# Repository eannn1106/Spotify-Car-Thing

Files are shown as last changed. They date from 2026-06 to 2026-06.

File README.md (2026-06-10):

# Spotify Car Thing_v1
A designated spotify display that can control playback, fetch track information including song duration, song artist, song album and displays lyrics. This spotify display is specially modified to fit in among non-coders by logging in wifi credentials throughout captive portal.
However for the one-time authentication part from Spotify API have to done it through a serial monitor by running the given code. 

****Note this device requires Spotify Premium and external sound system e.g. phone, laptop, speaker**


# Why I want to build this?
- A spotify car thing manufactured from Spotify costs over 30 USD, and for aesthetics reasons, I think that it is cool to have one sitting right in front of the car dashboard.
- The original spotify car thing doesn't support lyrics display and whenever I heard a song playing in my Spotify, I have the curiosity to seek for the lyrics. But I doesn't want the lyrics to pop out in the corner of my desktop. Instead I wanted a seperate display device for this.
- Spotify discontinued their Car Thing in 2022 which then I think there is a lot of potential with this product it can bring to the car interior industry and music industry.
# Why you should prefer this and not other products?
- Cheap and affordable. Products like this only uses microcontrollers to access the API through internet to get lyrics and fetch track information and display it through a friendly budget display screen.
- Doesn't have to be a "car thing", it can be a display on your table for decorating purposes.
- Flexibility. Instead of using bluetooth, this device requires wifi which is much more wider and higher bandwidth compared to bluetooth.
- Low power required. This device only borrows a little port from your device to operate, and doesn't requires a power plug for this device to work.
# How to setup? (one-time setup)
1. Download the sketch file code into Arduino IDE or other code editor platforms that support sketch files.
2. Go to https://developer.spotify.com/dashboard and click create apps to have access to the API.
3. For the redirect url, enter this url https://spotifyesp32.vercel.app/api/spotify/callback
4. Copy the client ID and client secret in the developer page.
**image from developer.spotify.com
5. Enter the client ID and client secret at the 16th and 17th row.
6. Plug in the Spotify Car Thing into your laptop or desktop.
7. Compile and upload the code into the esp32 devkit_v1.
8. Open the serial monitor.
9. Connect to the wifi called "SpotifyCarThing" with the password "spotify123".
10. It will bring you to a captive web portal for you to enter your wifi credentials. 
11. Enter your wifi credentials in the text box, it can be a home wifi or your personal hotspot from your device. (the wifi have to be in 2.4 GHz Band) **(IOS user have to turn on maximise compatibility)**
12. From the serial monitor, copy the authentication url provided and copy it into your browser to login and authenticate your spotify account. 
13. Play something on your Spotify app!
# How to use it (in the long run)
1. Powering it up
   - Connect this to a 5v power supply through the micro usb slot in the left hand side of the device. A USB port from your laptop/desktop or a standard 5v USB wall charger will do.
2. Play/Pause toggle switch
   - Locate the middle from top to bottom switch to play or pause the current track.
3. Skip track switch
   - Locate the most bottom from top to bottom switch to skip forward the current playing track.
4. Previous track switch
   - Locate the toppest from top to bottom switch to skip backwards the current playing track.
5. Reset WiFi hidden switch
   - Long press on all 3 switch for 3 seconds the reset the WiFi.
   - Repeat the process to enter wifi credentials
# How it works
1. Authentication mode

 
 **image from developer.spotify.com

- Refresh token is the permanent credential while access token expires every hour but Spotify ESP32 library handles renewal automatically.
- Spotify ESP32 library will generate an authentication url with random state tokens that cant be duplicated and print it in the serial monitor.
- After authentication, spotify redirects to vercel.app callback which also handled by spotify ESP32 library.
- Callback exchanges authentication code for refresh token and access token.
- ESP32 receives these tokens by using this sp.handle_client() function and refresh token will be saved by using SPIFFS library in the flash memory.
2. Controlling playback flow
- By setting the scopes from https://developer.spotify.com/documentation/web-api/concepts/scopes, it allows us to make a few requests to spotify api and obtain information, for this specific project I've set the scopes to user-read-playback-state, user-modify-playback-state and user-read-currently-playing.
- Refresh token is loaded and access token is constantly be renewed by Spotify ESP32 library on first API call.
- API will be called for every 1 second to obtain the real position of the specific track position.
- Obtained data from the web api will be in Json document form and will be parsed into each variable.
3. Obtaining lyrics from lrclib API
- ESP32 will make HTTP requests to obtain the lyrics in Json document form containing synced lyrics and unsynced lyrics.
4. Synced lyrics
- Lrclib API is a free open source lyrics API, and obtained synced lyrics comes with the format of milisecond timestamp where convertions will be handled locally by ESP 32.
- ESP32 will create it's own timestamp to match with the synced lyrics' timestamp whenever the current track started playing.
5. Wifi login
- ESP32 will first check if there is any saved networks in the flash memory, if no it will execute captive portal.
- ESP32 will create a Wifi hotspot "SpotifyCarThing" by switching mode to Access point mode.
- DNSServer intercepts all DNS queries and redirect to the IP address of your ESP32.
- Browser automatically opens the setup page for user to type in their wifi credentials.
- After user types their wifi credentials, it will be saved into the flash memory of ESP32 using the Prefences library.
- ESP32 switches to station mode, and the captive portal will be closed.
- Right now, ESP32 will already have the saved wifi credentials in their flash memory, ESP32 will restart and check then connects to the wifi in the flash memory.
6. TFT display management
- Rewriting the entire screen every second will cause constant visible flickering. Instead, each displayed element in NowPlayingInfo is being tracked by the variables locally.
- If the displayed elements doesnt match the current element, it will be updated.
- Text sizing is dynamic as size 2 is used by defauly and will automatically drop the size to 1 if the text is wider than the screen width which is 480px.

# Parts needed
[Bill of Materials](BOM.csv)

# How to assemble?
1. Prepare all the parts stated in the BOM
2. Solder the keyboard switches onto the pcb according to the silkscreen layer.
3. We'll start with attatching the ESP32 into the PCB via the connector sockets.
4. Secure the PCB into the 4 tower screws with 4x 4mm m3 self-tapped screws.
5. Insert and attach the 3.5'' rpi display throgh the hole of the case and into the pcb's connector header pins.
6. Attach the keycaps to the keyboard switch for easier control of buttons.

# Libraries installed
1. Spotify Esp32 - https://github.com/FinianLandes/SpotifyEsp32.git
2. Arduino Json - https://github.com/bblanchon/ArduinoJson.git
3. TFT_eSPI - https://github.com/Bodmer/TFT_eSPI.git

# Schematics


# PCB

3D view of the PCB



To make the device more compact, I decided to add the ESP32 below the PCB.
# Case
The case is being held by 4 cantilever snaps at the four corners of the case.



The PCB is being screwed into these 4 screw towers using 4x M3 screws


I got the inspiration from a retro tv specifically this type.
 

The case looks boxy and have slight rounded edges on the side but, for the bottom of the case, I won't make it curved as it can't be tumbling down from bumpy roads. The controls are on the right hand side and the screen is on the left hand side of the case.

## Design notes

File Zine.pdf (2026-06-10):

CONTROL | THE | MUSIC

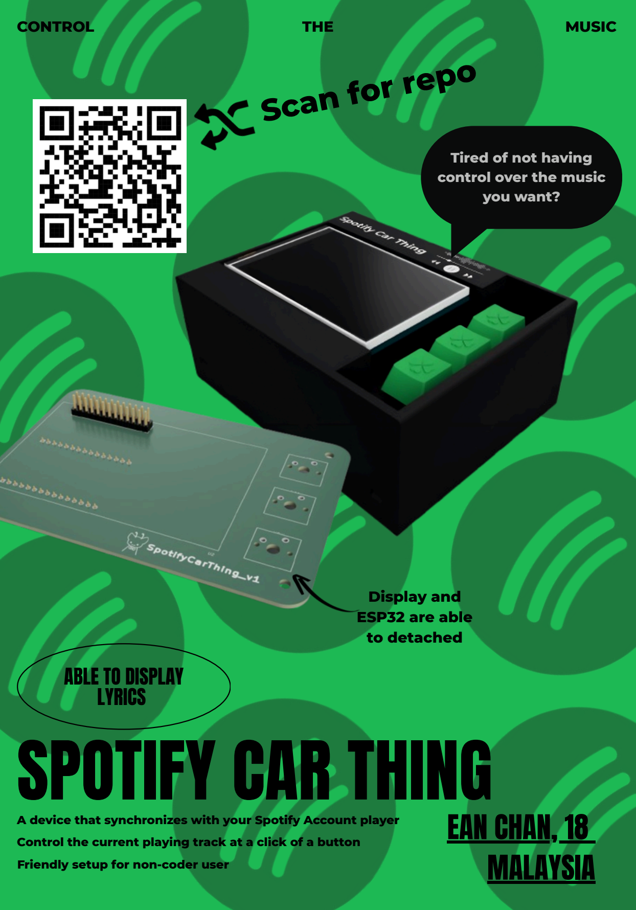
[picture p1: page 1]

# ABLE TO DISPLAY LYRICS

Tired of not having
control over the music
you want?

# Scan for repo

# EAN CHAN, 18 MALAYSIA

# SPOTIFY CAR THING

A device that synchronizes with your Spotify Account player Control the current playing track at a click of a button

Friendly setup for non-coder user

### Display and ESP32 are able to detached

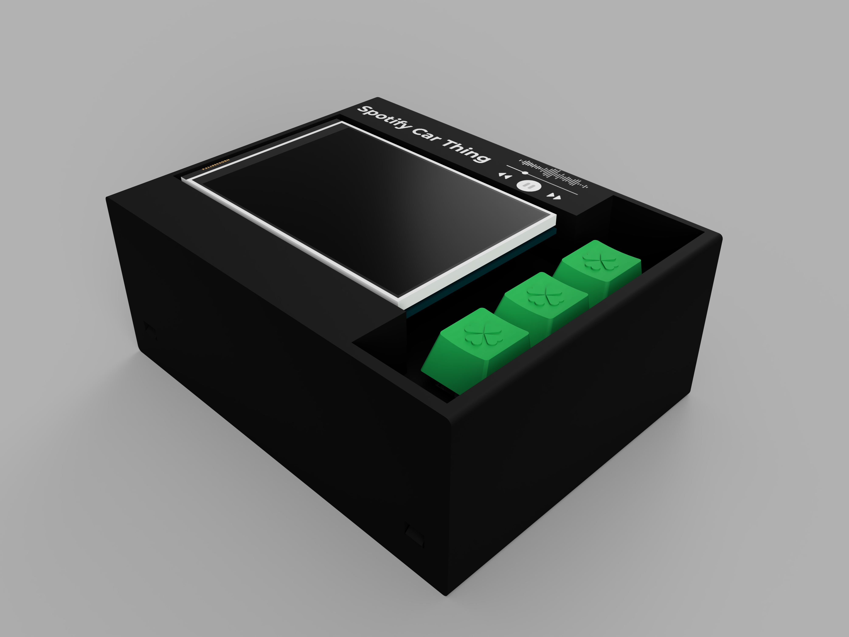
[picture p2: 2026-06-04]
Hardware/Spotify_Car_Thing__v1_(rendered case).png

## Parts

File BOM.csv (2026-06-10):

No. | Name | Quantity | Unit Price (RM) | Quantity Price (RM) | Unit Price (USD) | Quantity Price (USD) | Manufacturer | Code | Platform | Link
1 | ESP32 devkit v1 | 1 | 29 | 29 | 7.23 | 7.23 | Espressif Systems | NODEMCU-ESP32 | Cytron Marketplace | https://my.cytron.io/p-nodemcu-esp32
2 | 3.5 inch RPI display | 1 | 65 | 65 | 16.2 | 16.2 | Rasberry Pi | DS-TFT-3.5 | Cytron Marketplace | https://my.cytron.io/p-3.5-inch-tft-touch-screen-for-rpi-3b-3b-plus-4b
3 | Mechanical Keyboards switches | 3 | 0.16 | 0.48 | 0.04 | 0.12 | Akko Cream | - | Shopee | https://my.shp.ee/7XG1UPNv
4 | Keycaps | 3 | 2 | 6 | 0.5 | 1.5 | MKB | - | Shopee | https://my.shp.ee/X7Zdr3Vp
5 | PCB | 5 | 7.3 | 36.5 | 1.82 | 9.1 | JCLPCB | - | JCLPCB | https://cart.jlcpcb.com/quote?stencilLayer=2&stencilWidth=100&stencilLength=100&stencilCounts=5&plateType=1
6 | 4mm m3 screws | 4 | 0.26 | 1.04 | 0.06 | 0.24 | Shopee | - | Shopee | https://my.shp.ee/7uo4mKo9
Total(RM) |  |  |  | 138.02 | Total(USD) | 34.39

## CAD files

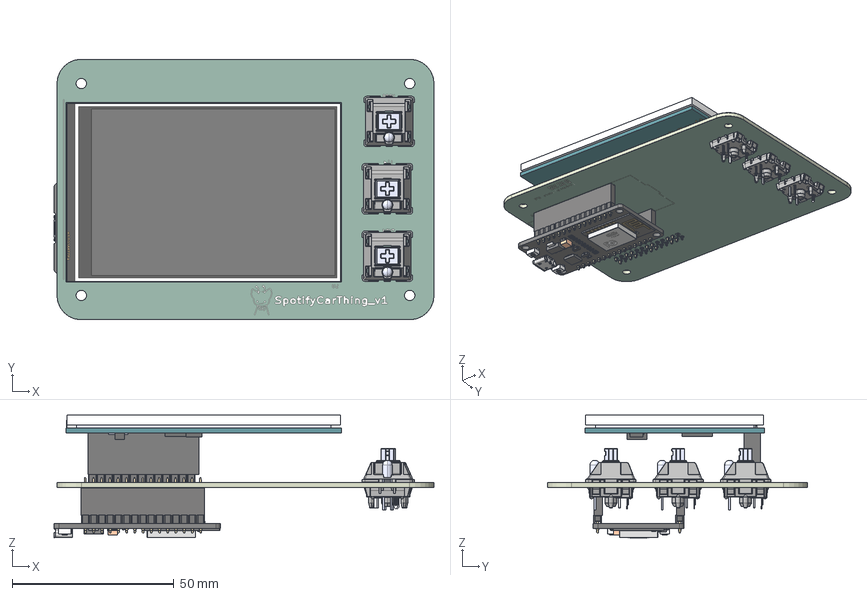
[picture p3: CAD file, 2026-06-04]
Hardware/Spotify Car Thing _v1 (pcb).step
117.4 x 80.5 x 37.9 mm
MX Öá °´¼ü¡ä_¨¹___¡§1 x 3
MX ס סͥ¨¢¨¬_¡§¡顧__ x 3
MXס ϞñLEDLEDLED x 3
MXÖá ÖáÌå µ×²¿ ¦Ì¡Á2__Ä¬ÈÏ_¨¢2____¨¨_ x 3
֫½ğ__Ĭɏ__¨¨_ x 3
PinHeader_2x13_P2.54mm_Vertical
User Library-3_5inch RPi LCD
PinSocket_1x15_P2.54mm_Vertical x 2
PCB
WIFI_CARD_2
RECTANGULARCHIP_2
MICROCHIP_2
TANCHIP_2
TRANSISTOR_3-LEG_2
RESISTOR1_2 x 11
RESISTOR2-32_2 x 2
TRANSISTOR_3-LEG2_2
BUTTONFLASH-13_2 x 2
BUTTONFLASH-14_2 x 2
USB_SOCKET_2
Spotify Car Thing_pad
Spotify Car Thing_silkscreen x 2
Spotify Car Thing_soldermask x 2
Spotify Car Thing_PCB

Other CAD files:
Hardware/Spotify Car Thing _v1 (src case).f3d

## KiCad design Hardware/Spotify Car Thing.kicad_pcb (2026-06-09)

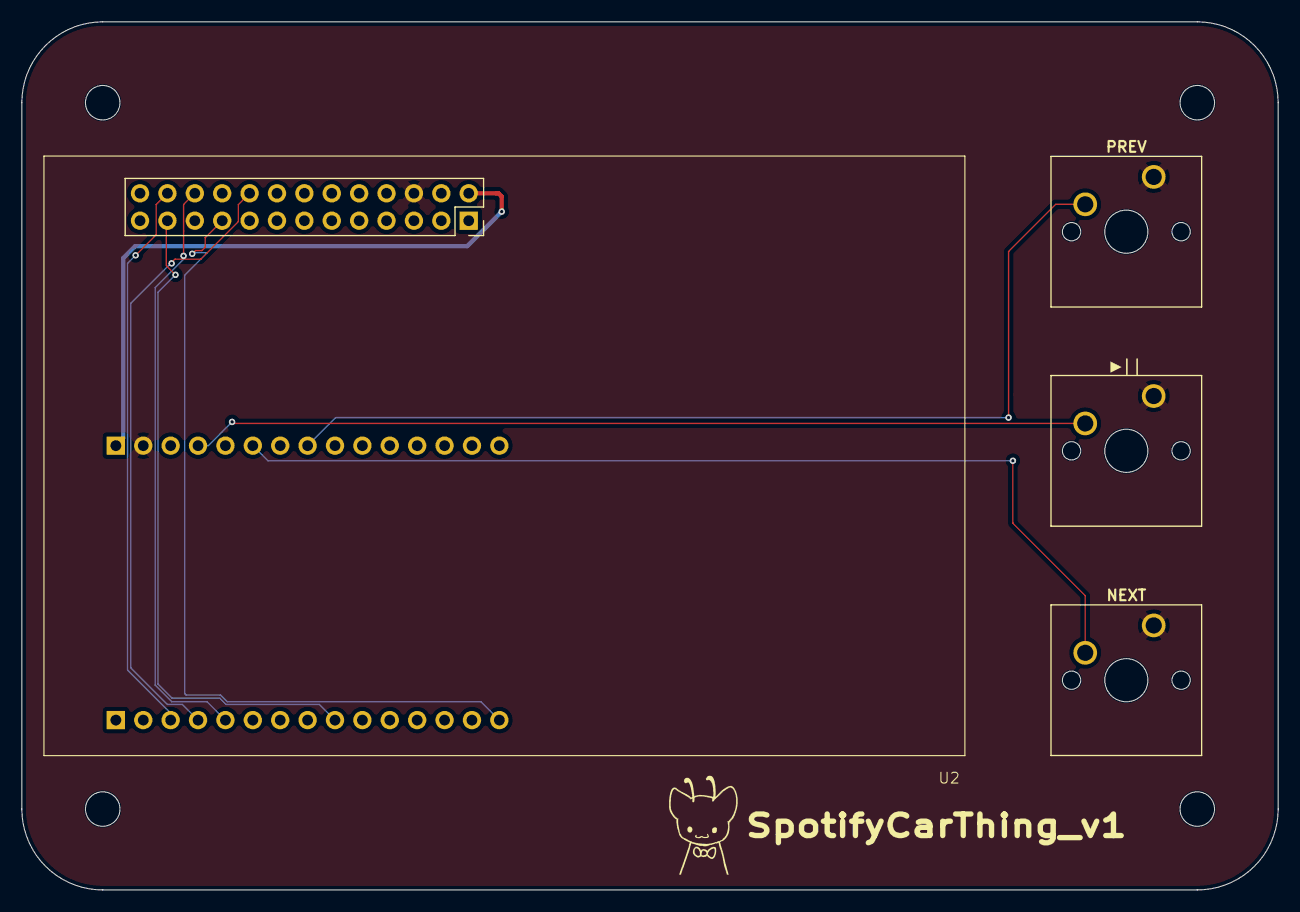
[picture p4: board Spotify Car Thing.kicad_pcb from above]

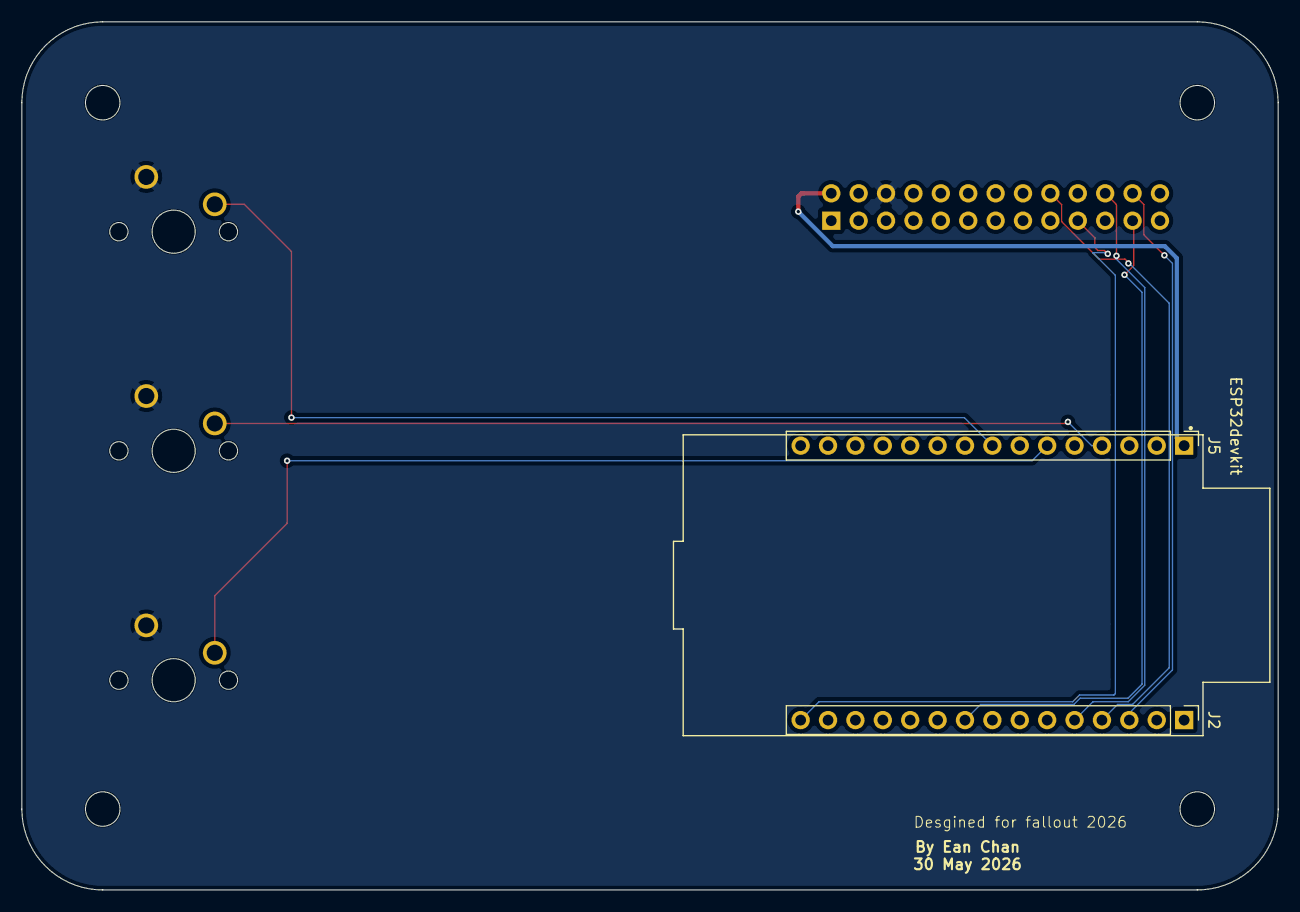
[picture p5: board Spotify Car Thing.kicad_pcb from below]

Board: 4 copper layers, 116.5 x 80.5 mm, 8 parts (3 on the bottom side), 10 nets.

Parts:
ESP32devkit: DEVKIT_V1_ESP32-WROOM-32; MODULE_DEVKIT_V1_ESP32-WROOM-32
J1: Conn_01x26_Pin; PinHeader_2x13_P2.54mm_Vertical
J2, J5: Conn_01x15_Socket; PinSocket_1x15_P2.54mm_Vertical
NEXT: SW_Push; SW_Cherry_MX_1.00u_PCB
PREV: SW_Push; SW_Cherry_MX_1.00u_PCB
U2: 3.5'' TFT RPI Display; 3.5'' TFT RPI Screen Display
▶︎||: SW_Push; SW_Cherry_MX_1.00u_PCB

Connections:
+5V: J1.2, J5.1
GND: J1.6, J5.2, NEXT.1, PREV.1, ▶︎||.1
unnamed: J1.18, J2.4
unnamed: J1.19, J2.15
unnamed: J1.22, J2.5
unnamed: J1.23, J2.9
unnamed: J1.24, J2.3
unnamed: J5.4, ▶︎||.2
unnamed: J5.6, NEXT.2
unnamed: J5.8, PREV.2

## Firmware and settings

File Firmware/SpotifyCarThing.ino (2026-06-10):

//libraries needed
#include <Arduino.h>
#include <WiFi.h>
#include <HTTPClient.h>
#include <ArduinoJson.h>
#include <SpotifyEsp32.h>
#include <SPIFFS.h>
#include <WebServer.h>
#include <Preferences.h>
#include <DNSServer.h>
#include <TFT_eSPI.h>

//credentials for spotify API
const char* SSID = "";
const char* PASSWORD = "";
const char* CLIENT_ID = "6ba7dd6f2f054dce97e27e81f39d124b";   //Enter your client ID 
const char* CLIENT_SECRET = "efb5a06d8f7748338bc8cc77807647b0";  //Enter your client secret

//button pins
#define BTN_PLAY_PAUSE 25
#define BTN_NEXT 27
#define BTN_PREV 12

//declare variables
String lastTrack = "";
String lastArtist = "";
String lastLyrics = "";
bool isPlaying = false;
unsigned long lastSpotifyCheck = 0;
unsigned long lastPositionMs = 0;
unsigned long lastPositionTime = 0;
unsigned long lastDurationMs = 0;
bool trackIsPlaying = false;
bool authComplete = false;
String spotifyAuthUrl = "";
bool wifiSaved = false;
bool wifiConnected = false;
String newWifiSSID = "";
String newWifiPass = "";
String savedRefreshToken = "";


//spotify controller
Spotify* sp_ptr = nullptr;
#define sp (*sp_ptr)

//Setup web server and DNS for captive portal
WebServer server(80);
DNSServer dnsServer;
Preferences prefs;
TFT_eSPI tft = TFT_eSPI();
//setup mode flag
bool isSetupMode = false;

//SET UP SCREEN DIMENSIONS
#define SCREEN_W 480
#define SCREEN_H 320

//SET COLORS
#define SPOTIFY_GREEN 0x25ca
#define DARK_GREY 0x2945
#define LIGHT_GREY 0xb596

//LAYOUT POSITIONS
#define HEADER_H 40
#define TRACK_Y 48
#define ARTIST_Y 90
#define ALBUM_Y 118
#define PROGRESS_Y 152
#define PROGRESS_H 16
#define PROGRESS_X 20
#define PROGRESS_W 440
#define LYRIC_Y 192
#define NEXT_LYRIC_Y 240

//DISPLAY FUNCTION
void initDisplay(){
  tft.begin();
  tft.setRotation(1);
  tft.fillScreen(TFT_BLACK);
  Serial.println("[TFT] ✅ Display initialized");
}

//Draw text centered horizontally
void drawCenteredText(String text, int y, uint16_t color, uint8_t size){
  tft.setTextSize(size);
  tft.setTextColor(color, TFT_BLACK);
  int textW = tft.textWidth(text);
  int x = (SCREEN_W - textW) / 2;
  if (x < 5) x = 5;
  tft.setCursor(x, y);
  tft.print(text);
}

//Clear line area
void clearLine(int y, int h){
  tft.fillRect(0, y, SCREEN_W, h, TFT_BLACK);
}

String truncateText(String text, uint8_t size, int maxWidth){
  tft.setTextSize(size);
  if(tft.textWidth(text) <= maxWidth){
    return text;
  }
  while(text.length() > 1 && tft.textWidth(text + "...") > maxWidth){
    text = text.substring(0, text.length() - 1);
  }
  return text + "...";
}

//Screen for booting
void showBootScreen(){
  tft.fillScreen(TFT_BLACK);

  tft.fillCircle(SCREEN_W/2, 100, 50, SPOTIFY_GREEN);
  tft.setTextColor(TFT_BLACK, SPOTIFY_GREEN);
  tft.setCursor(SCREEN_W/2 - 20, 85);
  tft.print("♪");

  tft.setTextColor(TFT_WHITE, TFT_BLACK);
  tft.setTextSize(3);
  drawCenteredText("Spotify Car Thing", 175, TFT_WHITE, 3);

  tft.setTextSize(1);
  drawCenteredText("Starting up...", 215, LIGHT_GREY, 1);
}

//wifi setup screen
void showWifiSetupScreen(){
  tft.fillScreen(TFT_BLACK);
  
  tft.fillRect(0, 0, SCREEN_W, HEADER_H, SPOTIFY_GREEN);
  tft.setTextColor(TFT_BLACK, SPOTIFY_GREEN);
  tft.setTextSize(2);
  drawCenteredText("WiFi Setup", 12, TFT_BLACK, 2);

  tft.setTextSize(3);
  tft.setTextColor(SPOTIFY_GREEN, TFT_BLACK);
  drawCenteredText("(())", 60, SPOTIFY_GREEN, 3);

  tft.setTextSize(2);
  tft.setTextColor(TFT_WHITE, TFT_BLACK);
  drawCenteredText("Connect to WiFi:", 110, TFT_WHITE, 2);

  tft.setTextSize(2);
  tft.setTextColor(SPOTIFY_GREEN, TFT_BLACK);
  drawCenteredText("SpotifyCarThing", 140, SPOTIFY_GREEN, 2);

  tft.setTextSize(1);
  tft.setTextColor(LIGHT_GREY, TFT_BLACK);
  drawCenteredText("Password: spotify123", 170, LIGHT_GREY, 1);

  tft.drawFastHLine(20, 190, SCREEN_W - 40, DARK_GREY);

  tft.setTextSize(1);
  tft.setTextColor(LIGHT_GREY, TFT_BLACK);
  drawCenteredText("Then open browser and enter", 200, LIGHT_GREY, 1);
  drawCenteredText("your home WiFi or personal hotspot credentials", 215, LIGHT_GREY, 1);
}

void showWifiConnectingScreen(String ssid){
  tft.fillScreen(TFT_BLACK);
  
  tft.fillRect(0, 0, SCREEN_W, HEADER_H, DARK_GREY);
  tft.setTextColor(TFT_WHITE, DARK_GREY);
  tft.setTextSize(2);
  drawCenteredText("Connecting to:", 100, LIGHT_GREY, 2);

  tft.setTextSize(2);
  tft.setTextColor(LIGHT_GREY, TFT_BLACK);
  drawCenteredText("Connecting to:", 100, LIGHT_GREY, 2);

  tft.setTextSize(2);
  tft.setTextColor(SPOTIFY_GREEN, TFT_BLACK);
  drawCenteredText(ssid, 130, SPOTIFY_GREEN, 2);

  tft.setTextSize(1);
  tft.setTextColor(LIGHT_GREY, TFT_BLACK);
  drawCenteredText("Please wait...", 175, LIGHT_GREY, 1);
}

void showWifiConnectedScreen(String ip){
  tft.fillScreen(TFT_BLACK);
  
  tft.fillRect(0, 0, SCREEN_W, HEADER_H, SPOTIFY_GREEN);
  tft.setTextColor(TFT_BLACK, SPOTIFY_GREEN);
  tft.setTextSize(2);
  drawCenteredText("WiFi Connected!", 12, TFT_BLACK, 2);

  tft.setTextSize(2);
  tft.setTextColor(TFT_WHITE, TFT_BLACK);
  drawCenteredText("IP Address:", 90, TFT_WHITE, 2);

  tft.setTextSize(2);
  tft.setTextColor(SPOTIFY_GREEN, TFT_BLACK);
  drawCenteredText(ip, 120, SPOTIFY_GREEN, 2);
}

void showWifiFailedScreen(){
  tft.fillScreen(TFT_BLACK);

  tft.fillRect(0, 0, SCREEN_W, HEADER_H, 0xf800);
  tft.setTextColor(TFT_WHITE, 0xf800);
  tft.setTextSize(2);
  drawCenteredText("WiFi Failed!", 12, TFT_WHITE, 2);

  tft.setTextSize(1);
  tft.setTextColor(LIGHT_GREY, TFT_BLACK);
  drawCenteredText("Check your WiFi name", 140, LIGHT_GREY, 1);
  drawCenteredText("and password then try again", 155, LIGHT_GREY, 1);
}

void showSpotifyAuthScreen(){
  tft.fillScreen(TFT_BLACK);
  
  tft.fillRect(0, 0, SCREEN_W, HEADER_H, SPOTIFY_GREEN);
  tft.setTextColor(TFT_BLACK, SPOTIFY_GREEN);
  tft.setTextSize(2);
  drawCenteredText("Spotify Login", 12, TFT_BLACK, 2);

  tft.setTextSize(2);
  tft.setTextColor(TFT_WHITE, TFT_BLACK);
  drawCenteredText("Open Serial monitor in Arduino IDE", 70, TFT_WHITE, 2);
  drawCenteredText("and copy the URL", 100, TFT_WHITE, 2);
  drawCenteredText("to your browser", 130, TFT_WHITE, 2);

  tft.drawFastHLine(20, 160, SCREEN_W - 40, DARK_GREY);

  tft.setTextSize(1);
  tft.setTextColor(LIGHT_GREY, TFT_BLACK);
  drawCenteredText("Login to Spotify once and works forever", 175, LIGHT_GREY, 1);
  drawCenteredText("Waiting for login...", 215, SPOTIFY_GREEN, 1);
}
void showResetCountdown(int seconds){
  if(seconds == 3){
    tft.fillScreen(TFT_BLACK);
    tft.fillRect(0, 0, SCREEN_W, HEADER_H, 0xf800);
    tft.setTextColor(TFT_WHITE, 0xf800);
    tft.setTextSize(2);
    drawCenteredText("Factory Reset!", 12, TFT_WHITE, 2);

    tft.setTextSize(1);
    tft.setTextColor(LIGHT_GREY, TFT_BLACK);
    drawCenteredText("Release buttons to cancel", 60, LIGHT_GREY, 1);
  }

  //update the countdown no.
  clearLine(100, 80);
  tft.setTextSize(6);
  tft.setTextColor(0xf800, TFT_BLACK);
  drawCenteredText(String(seconds), 110, 0xf800, 6);

  tft.setTextSize(1);
  tft.setTextColor(LIGHT_GREY, TFT_BLACK);
  drawCenteredText("seconds...", 175, LIGHT_GREY, 1);
}

void showResetCancelled(){
  tft.fillScreen(TFT_BLACK);
  tft.setTextSize(2);
  drawCenteredText("Reset Cancelled", 140, TFT_WHITE, 2);
  delay(1000);
}

String displayedTrack = "";
String displayedArtist = "";
String displayedAlbum = "";
String displayedLyric = "";
String displayedNextLyric = "";

void drawNowPlayingLayout(){
  tft.fillScreen(TFT_BLACK);

  tft.fillRect(0, 0, SCREEN_W, HEADER_H, DARK_GREY);
  tft.setTextColor(SPOTIFY_GREEN, DARK_GREY);
  tft.setTextSize(2);
  tft.setCursor(10, 12);
  tft.print("NOW PLAYING");

  tft.drawRoundRect(PROGRESS_X, PROGRESS_Y, PROGRESS_W, PROGRESS_H, 4, 0X4A69);

  tft.drawFastHLine(20, LYRIC_Y - 12, SCREEN_W - 40, DARK_GREY);
}

void updateTrackInfo(String track, String artist, String album){
  if(track == displayedTrack && artist == displayedArtist && album == displayedAlbum){
    return;
  }
  displayedTrack = track;
  displayedArtist = artist;
  displayedAlbum = album;

  clearLine(TRACK_Y, 95);

  //track name
  tft.setTextSize(2);
  uint8_t trackSize = (tft.textWidth(track) > SCREEN_W - 20) ? 1 : 2;
  drawCenteredText(track, TRACK_Y, TFT_WHITE, trackSize);

  //artist name
  tft.setTextSize(2);
  uint8_t artistSize = (tft.textWidth(artist) > SCREEN_W - 20) ? 1 : 2;
  drawCenteredText(artist, ARTIST_Y, SPOTIFY_GREEN, artistSize);

  //album name
  drawCenteredText(album, ALBUM_Y, LIGHT_GREY, 1);
}

void updateProgressBar(unsigned long positionMs, unsigned long durationMs){
  if(durationMs == 0){
    return;
  }
  float progress = (float)positionMs / (float)durationMs;
  if(progress > 1.0){
    progress = 1.0;
  }

  int filled = (int)(progress * (PROGRESS_W - 4));

  if(filled > 0){
    tft.fillRoundRect(PROGRESS_X + 2, PROGRESS_Y + 2, filled, PROGRESS_H - 4, 3, SPOTIFY_GREEN);
  }

  if(filled < PROGRESS_W - 4){
    tft.fillRect(PROGRESS_X + 2 + filled, PROGRESS_Y + 2, PROGRESS_W - 4 - filled, PROGRESS_H - 4, TFT_BLACK);
  }

  int posMin = (positionMs / 1000) / 60;
  int posSec = (positionMs / 1000) % 60;
  int durMin = (durationMs / 1000) / 60;
  int durSec = (durationMs / 1000) % 60;

  char timeStr[20];
  sprintf(timeStr, "%d:%02d / %d:%02d", posMin, posSec, durMin, durSec);

  tft.fillRect(PROGRESS_X, PROGRESS_Y + PROGRESS_H + 3, PROGRESS_W, 14, TFT_BLACK);

  tft.setTextSize(1);
  drawCenteredText(String(timeStr), PROGRESS_Y + PROGRESS_H + 5, LIGHT_GREY, 1);
}

void updateLyrics(String currentLine, String nextLine){
  if(currentLine == displayedLyric && nextLine == displayedNextLyric){
    return;
  }
  displayedLyric = currentLine;
  displayedNextLyric = nextLine;

  clearLine(LYRIC_Y - 5, SCREEN_H - LYRIC_Y + 5);

  if(!currentLine.isEmpty()){
    tft.setTextSize(2);
    uint8_t lyricSize = (tft.textWidth(currentLine) > SCREEN_W - 20) ? 1 : 2;
    drawCenteredText(currentLine, LYRIC_Y, TFT_WHITE, lyricSize);
  }
  
  if(!nextLine.isEmpty()){
    tft.setTextSize(2);
    uint8_t nextSize = (tft.textWidth(nextLine) > SCREEN_W - 20) ? 1 : 2;
    drawCenteredText(nextLine, NEXT_LYRIC_Y, LIGHT_GREY, nextSize);
  }
}

void updatePlayPauseIcon(bool playing){
  static const unsigned char PROGMEM image_music_pause_bits[] = {0xf9,0xf0,0x89,0x10,0x89,0x10,0x89,0x10,0x89,0x10,0x89,0x10,0x89,0x10,0x89,0x10,0x89,0x10,0x89,0x10,0x89,0x10,0x89,0x10,0x89,0x10,0x89,0x10,0xf9,0xf0,0x00,0x00};
  static const unsigned char PROGMEM image_music_play_bits[] = {0xc0,0x00,0xe0,0x00,0x98,0x00,0x86,0x00,0x81,0x80,0x80,0x60,0x80,0x18,0x80,0x06,0x80,0x18,0x80,0x60,0x81,0x80,0x86,0x00,0x98,0x00,0xe0,0x00,0xc0,0x00,0x00,0x00};
  tft.fillRect(SCREEN_W - 35, 8, 25, 25, DARK_GREY);
  tft.setTextSize(2);
  if(playing){
    tft.setTextColor(SPOTIFY_GREEN, DARK_GREY);
    tft.drawBitmap(SCREEN_W - 32, 12, image_music_play_bits, 15, 16, 0xffff);
  }
  else{
    tft.setTextColor(LIGHT_GREY, DARK_GREY);
    tft.drawBitmap(SCREEN_W - 32, 12, image_music_pause_bits, 12, 16, 0xffff);
  }
}

void showNothingPlaying(){
  if(displayedTrack == "NOTHING_PLAYING"){
    return;
  }
  displayedTrack = "NOTHING_PLAYING";

  tft.fillScreen(TFT_BLACK);
  tft.fillRect(0, 0, SCREEN_W, HEADER_H, DARK_GREY);
  tft.setTextColor(LIGHT_GREY, DARK_GREY);
  tft.setTextSize(2);
  drawCenteredText("Spotify Car Thing", 12, LIGHT_GREY, 2);

  tft.setTextSize(3);
  tft.setTextColor(DARK_GREY, TFT_BLACK);
  drawCenteredText("♪", 120, DARK_GREY, 3);

  tft.setTextSize(2);
  tft.setTextColor(LIGHT_GREY, TFT_BLACK);
  drawCenteredText("Nothing is playing", 180, LIGHT_GREY, 2);

  tft.setTextSize(1);
  tft.setTextColor(DARK_GREY, TFT_BLACK);
  drawCenteredText("Open Spotify and play something!", 220, DARK_GREY, 1);
}

void clearWifiCredentials(){
  prefs.begin("wifi", false);
  prefs.clear();
  prefs.end();
  Serial.println("[PREFS] ✅ WiFi credentials cleared!");
}

//clear saved token
void clearSavedToken(){
  if(SPIFFS.exists("/spotify_refresh.txt")){
    SPIFFS.remove("/spotify_refresh.txt");
    Serial.println("[CLEAR] ✅ Token cleared!");
  }
}

//factory reset - clear both wifi and spotify token
void factoryReset(){
  //Clear WiFi (Prefences)
  clearWifiCredentials();
  //Clear Spotify token (SPIFFS)
  Serial.println("[RESET] ✅ Factory reset complete!");
  tft.setTextSize(2);
  tft.fillScreen(TFT_BLACK);
  drawCenteredText("Resetting...", 140, 0xf800, 2);
}

void checkResetButton(){
  if (digitalRead(BTN_PLAY_PAUSE) == LOW && digitalRead(BTN_NEXT) == LOW && digitalRead(BTN_PREV) == LOW){
    Serial.println("[RESET] Hold all buttons for 3 seconds to restart 🔄️");
    for(int i = 3; i > 0; i--){
      Serial.printf("Factory resetting in %d seconds...\n", i);
      showResetCountdown(i);
      delay(1000);

      if(digitalRead(BTN_PLAY_PAUSE) == HIGH || digitalRead(BTN_NEXT) == HIGH || digitalRead(BTN_PREV) == HIGH){
        Serial.println("[RESET] ❌ CANCELLED RESET");
        showResetCancelled();
        displayedTrack = "";
        displayedAlbum = "";
        displayedAlbum = "";
        displayedLyric = "";
        drawNowPlayingLayout();
        return;
      }
    }
    factoryReset();
    delay(200);
    ESP.restart();
  }
}
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
void loop(){
  //Check for RESET BUTTON (HOLD ALL BUTTONS FOR 3 sec)
  checkResetButton();
  buttons();
  
  if(savedRefreshToken.length() > 10){
    //check spotify every 1 second
    unsigned long now = millis();
    unsigned long livePosition = 0;
    if (trackIsPlaying && lastPositionTime > 0){
      livePosition = lastPositionMs + (now - lastPositionTime);
    }
    static unsigned long lastLyricDisplay = 0;
    if (millis() - lastLyricDisplay >= 1000){
      lastLyricDisplay = millis();

      if(trackIsPlaying && !lastLyrics.isEmpty() && livePosition > 0){
        displaySyncedLyrics(lastLyrics, livePosition);
        updateProgressBar(livePosition, lastDurationMs);
      }
    }

    if(now - lastSpotifyCheck >= 1000){
      lastSpotifyCheck = now;
      checkResetButton();
      //Get full playback state to extract progress
      JsonDocument filter;
      filter["progress_ms"] = true;  
      filter["item"]["name"] = true;
      filter["item"]["album"]["name"] = true;
      filter["item"]["artists"][0]["name"] = true;
      filter["item"]["duration_ms"] = true;
      filter["is_playing"] = true;

      response playbackState = sp.get_currently_playing_track(filter);

      if(playbackState.status_code == 200){
        int currentPosition = playbackState.reply["progress_ms"];        //extract current position duration of track
        int trackLengthMs = playbackState.reply["item"]["duration_ms"]; //extract length duration of track
        String currentTrack = playbackState.reply["item"]["name"];
        String currentAlbum = playbackState.reply["item"]["album"]["name"];
        String currentArtist = playbackState.reply["item"]["artists"][0]["name"];
        bool currentlyPlaying = playbackState.reply["is_playing"];

        //update playing state
        isPlaying = currentlyPlaying;
        //update local position tracking
        lastDurationMs = trackLengthMs;
        lastPositionMs = currentPosition;
        lastPositionTime = millis();
        trackIsPlaying = currentlyPlaying;
        updateProgressBar(currentPosition, trackLengthMs);
        //calculate position in seconds and minutes
        int posMin = (currentPosition / 1000) / 60;
        int posSec = (currentPosition / 1000) % 60;
        int trackMin = (trackLengthMs / 1000) / 60;
        int trackSec = (trackLengthMs / 1000) % 60;
      
        if (!currentTrack.isEmpty()){
          updateTrackInfo(currentTrack, currentArtist, currentAlbum);
          updatePlayPauseIcon(currentlyPlaying);
          Serial.println("───────────────────────────────────────────────────");
          Serial.println("🎵 NOW PLAYING");
          Serial.println(" 📻  " + currentTrack);
          Serial.println(" 🧑‍🎤 Artist: " + currentArtist);
          Serial.println(" 📖 Album: " + currentAlbum);
          Serial.printf(" ⏱️ Position: %d:%02d / %d:%02d \n", posMin, posSec, trackMin, trackSec);
          Serial.printf(" ⏯️ Play/Pause: GPIO %d\n", BTN_PLAY_PAUSE);
          Serial.printf(" ⏭️ Next:       GPIO %d\n", BTN_NEXT);
          Serial.printf(" ⏮️ Previous:   GPIO %d\n", BTN_PREV);
          Serial.println("───────────────────────────────────────────────────");

          //change another track
          if (currentTrack != lastTrack && !currentTrack.isEmpty()){
            lastTrack = currentTrack;
            lastArtist = currentArtist;
            //fetch lyrics with track name, artist, album and duration
            int durationSec = trackLengthMs / 1000;
            lastLyrics = fetchLyrics(currentTrack, currentArtist, currentAlbum, durationSec);
            if(lastLyrics.isEmpty()){
              Serial.println("[LYRICS] No lyrics found for this song");
            }
            else{
              Serial.println("[LYRICS] ✅ Lyrics loaded!");
            }
          }
        }  
      } 
      else if(playbackState.status_code == 204){
        trackIsPlaying = false;
        isPlaying = false;
        Serial.println("[SPOTIFY] Nothing is playing");
        showNothingPlaying();
      }
      else{
        //request failed
        Serial.printf("[SPOTIFY] ❌ Failed to get playback state: %d\n", playbackState.status_code);
        Serial.printf("[WiFi] Signal: %d dBm\n", WiFi.RSSI());
      }
    }
  }
}
